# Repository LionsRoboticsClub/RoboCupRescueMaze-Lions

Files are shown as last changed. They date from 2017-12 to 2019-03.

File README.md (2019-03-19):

# RoboCupRescueMaze-Lions DONE TMR 201X
RoboCup Rescue Maze 

//CAD Render 2 months before final prototype -> https://autode.sk/2EDeenq

TODO ---- Add new Online Render 

This Repository holds all the data regarding the Lions RC Maze Robot - 2018.

Some of the content that can be found here is: 

PCBs
  Eagle files
  Gerber files
Arduino Code
  Classes
  Main
CADs
  Each piece is uploaded here for further reference and 3D printing

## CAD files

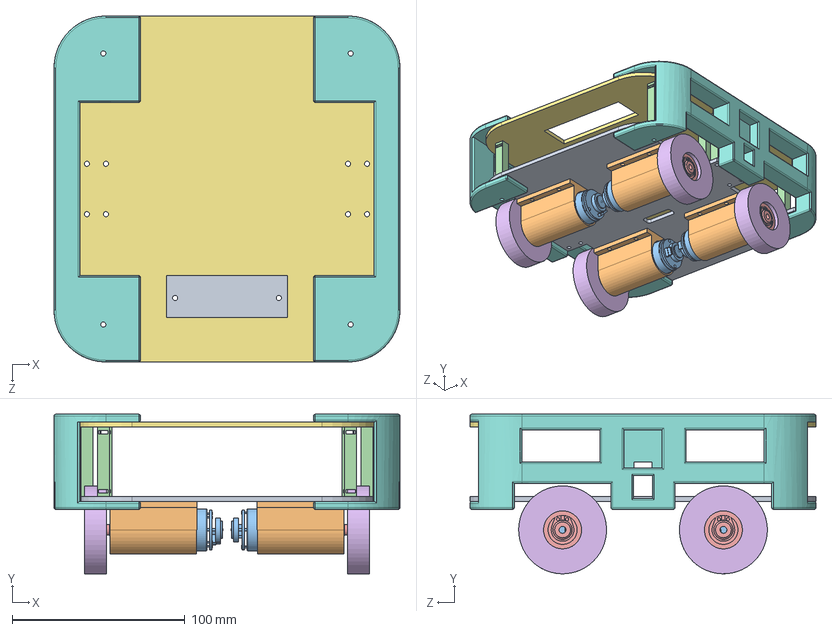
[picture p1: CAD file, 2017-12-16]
Cads/MazeRobot.SLDASM
200.0 x 92.3 x 200.0 mm
MazeBase
pololuMotorHolder x 4
Pololu 25D gear motor with encoder part no 2275 x 4
poste x 12
Snap_Hub_4mmx050 x 4
wheel x 4
MazeTop
LateralBumper x 2

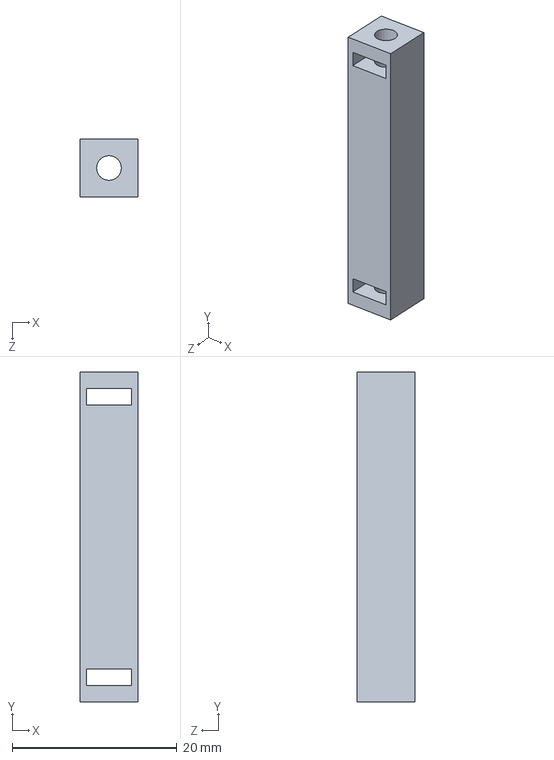
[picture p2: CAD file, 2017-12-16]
Cads/poste.SLDPRT
7.00 x 40.0 x 7.00 mm

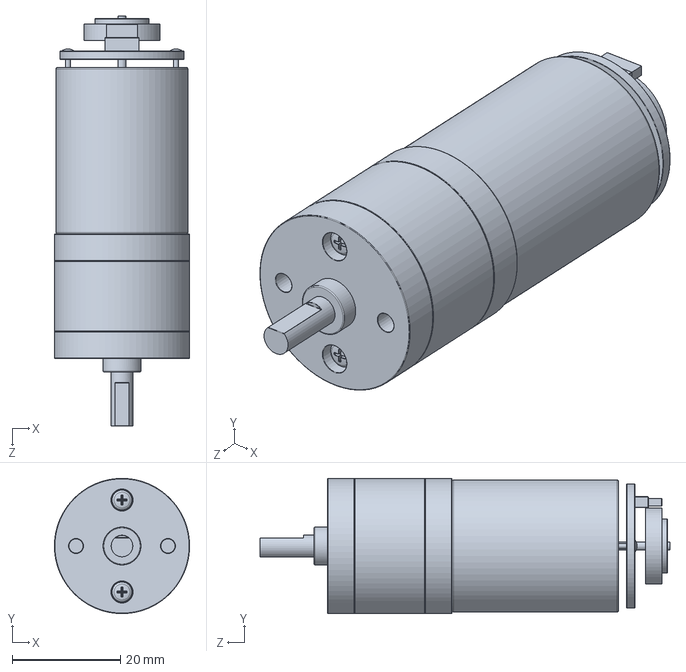
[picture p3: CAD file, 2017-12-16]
Cads/Pololu 25D gear motor with encoder part no 2275.SLDPRT
25.0 x 25.0 x 75.8 mm

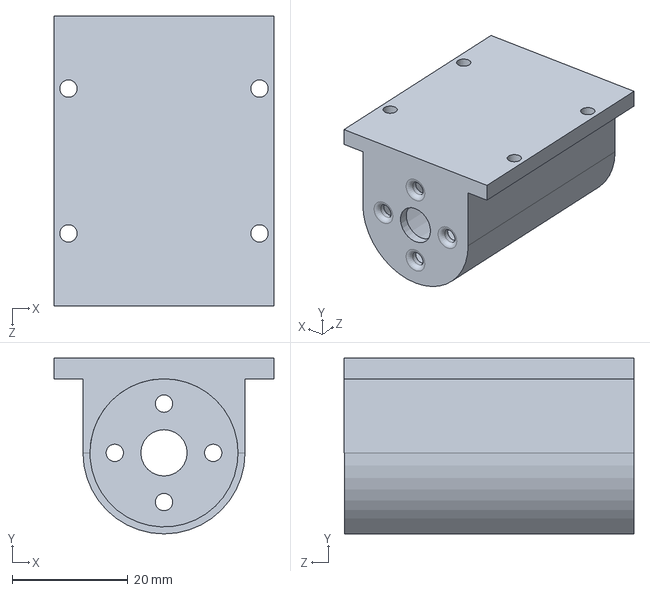
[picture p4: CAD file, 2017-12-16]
Cads/pololuMotorHolder.SLDPRT
38.0 x 30.4 x 50.0 mm

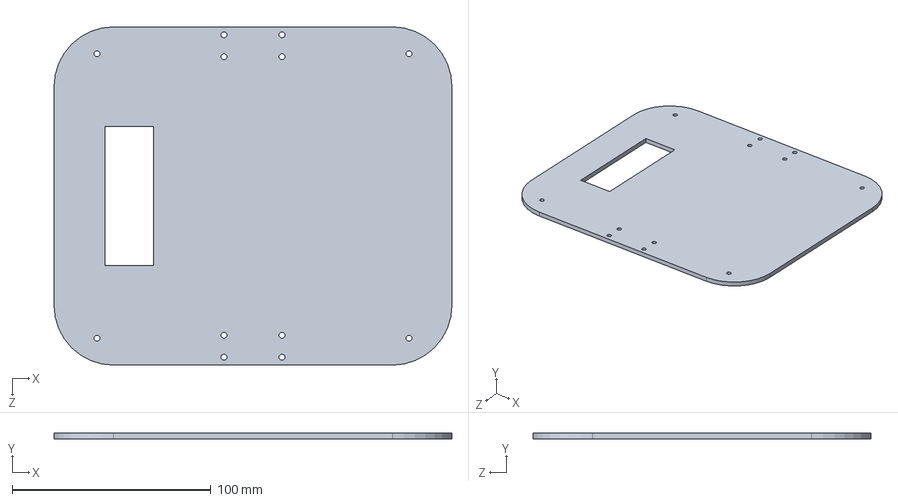
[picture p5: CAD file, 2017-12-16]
Cads/MazeTop.SLDPRT
200.0 x 3.00 x 170.0 mm

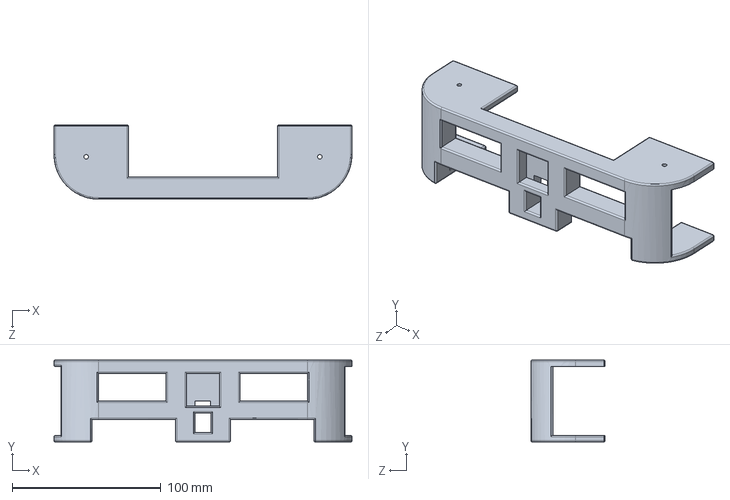
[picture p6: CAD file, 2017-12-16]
Cads/LateralBumper.SLDPRT
200.0 x 55.0 x 50.0 mm

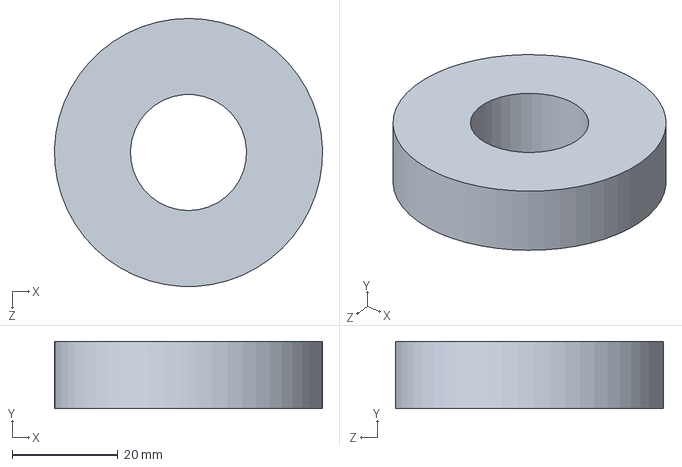
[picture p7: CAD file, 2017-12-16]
Cads/wheel.SLDPRT
50.8 x 12.7 x 50.8 mm

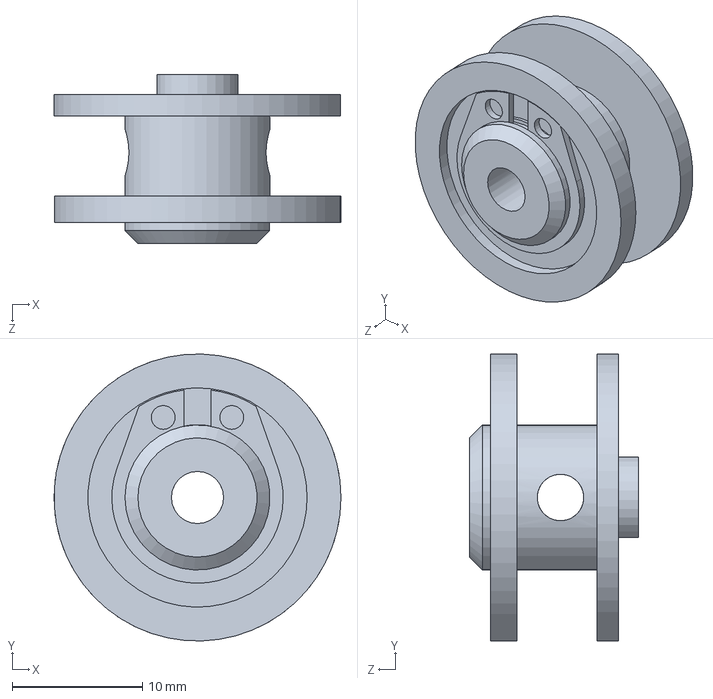
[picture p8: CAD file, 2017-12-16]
Cads/Snap_Hub_4mmx050.SLDPRT
22.0 x 22.0 x 13.0 mm

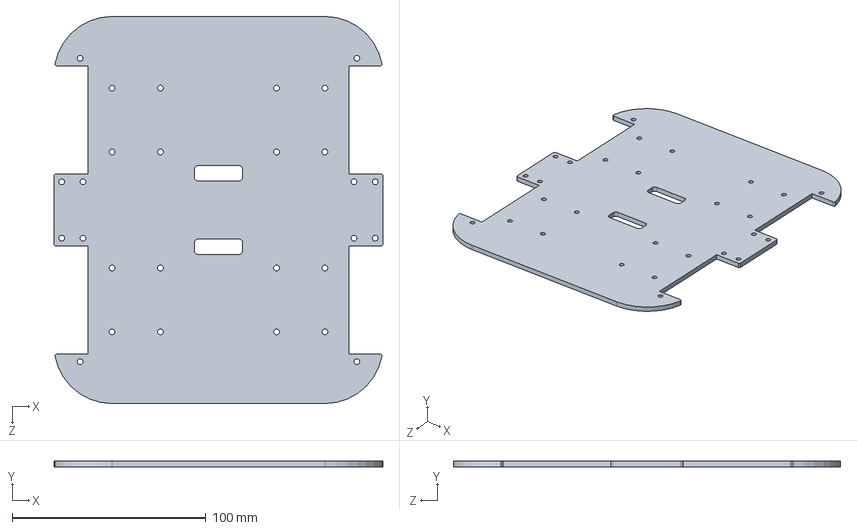
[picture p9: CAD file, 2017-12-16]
Cads/MazeBase.SLDPRT
170.0 x 3.00 x 200.0 mm

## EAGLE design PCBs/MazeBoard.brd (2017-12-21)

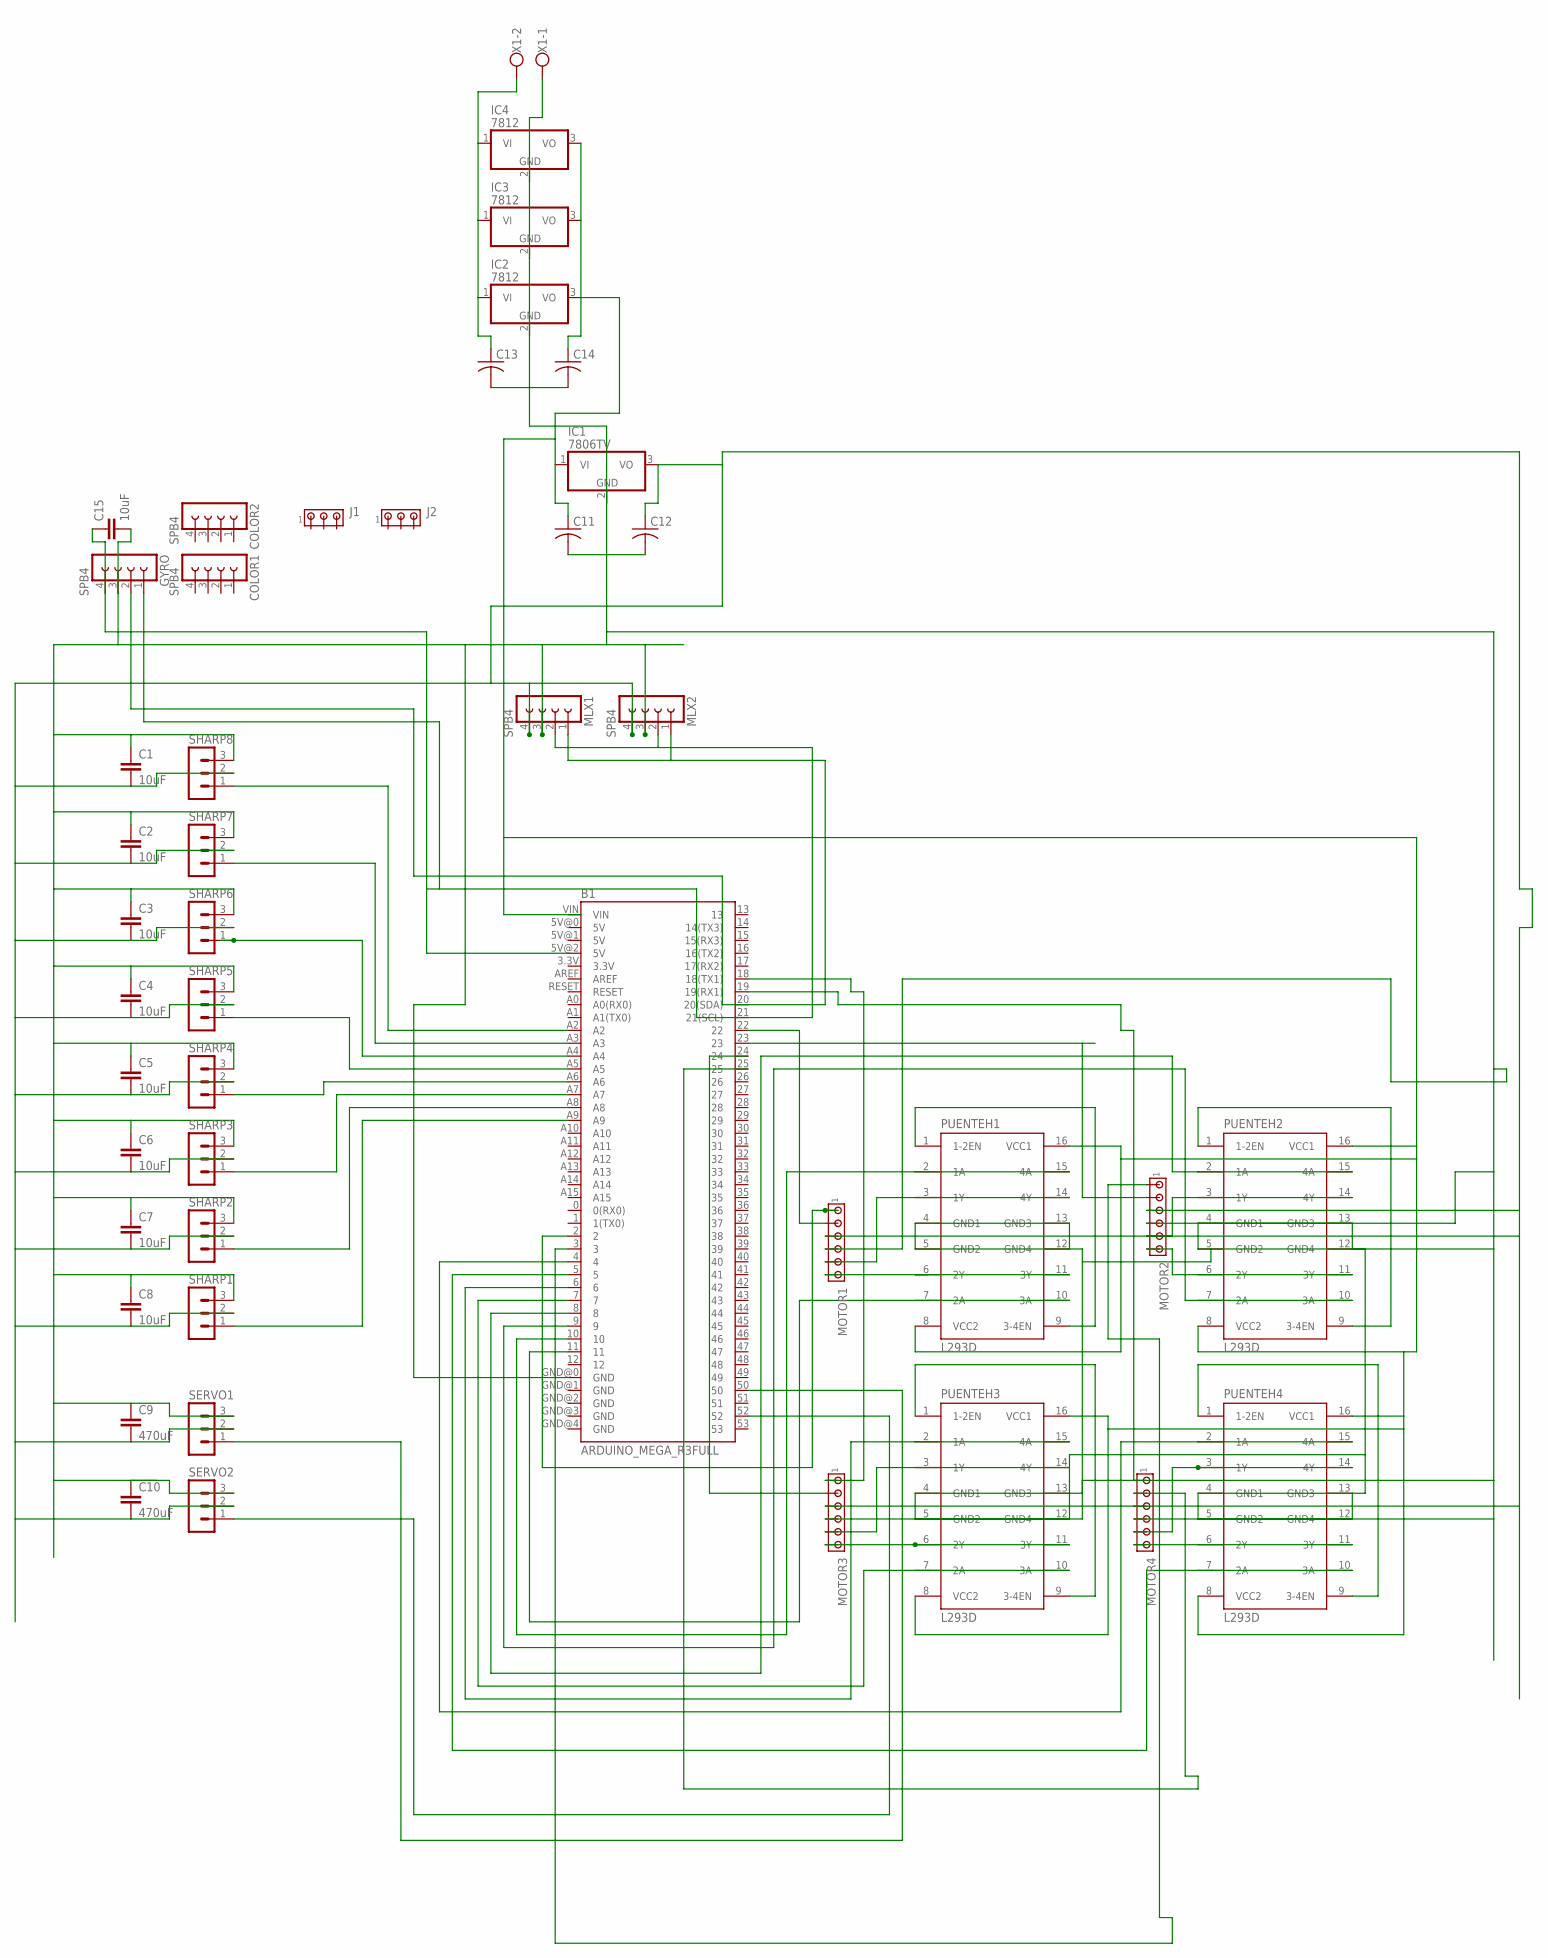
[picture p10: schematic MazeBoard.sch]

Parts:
B1: ARDUINO_MEGA_R3FULL; ARDUINO_MEGA
C1, C2, C3, C4, C5, C6, C7, C8, C15: 10uF; C2.5-3
C9, C10: 470uF; C2.5-3
C11, C12, C13, C14: C-US025-024X044; C025-024X044
COLOR1, COLOR2: SPB4
GYRO: SPB4
IC1: 7806TV; TO220V
IC2, IC3, IC4: 7812; TO220V
J1, J2: MTA03-100; 10X03MTA
MLX1, MLX2: SPB4
MOTOR1, MOTOR2, MOTOR3, MOTOR4: MTA06-100; 10X06MTA
PUENTEH1, PUENTEH2, PUENTEH3, PUENTEH4: L293D; DIL16
SERVO1, SERVO2: MA03-1
SHARP1, SHARP2, SHARP3, SHARP4, SHARP5, SHARP6, SHARP7, SHARP8: MA03-1
X1: W237-102

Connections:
6V: C1.2, C2.2, C3.2, C4.2, C5.2, C6.2, C7.2, C8.2, C9.2, C10.2, C12.1, IC1.3 (VO), MLX1.4, MLX2.4, MOTOR1.3, MOTOR2.3, MOTOR3.3, MOTOR4.3, SERVO1.2, SERVO2.2, SHARP1.2, SHARP2.2, SHARP3.2, SHARP4.2, SHARP5.2, SHARP6.2, SHARP7.2, SHARP8.2
GND: B1.GND@0 (GND), C1.1, C2.1, C3.1, C4.1, C5.1, C6.1, C7.1, C8.1, C9.1, C10.1, C11.2, C12.2, C13.2, C14.2, C15.2, GYRO.3, IC1.2 (GND), IC2.2 (GND), IC3.2 (GND), IC4.2 (GND), MLX1.3, MLX2.3, MOTOR1.4, MOTOR2.4, MOTOR3.4, MOTOR4.4, PUENTEH1.4 (GND1), PUENTEH1.5 (GND2), PUENTEH1.12 (GND4), PUENTEH1.13 (GND3), PUENTEH2.4 (GND1), PUENTEH2.5 (GND2), PUENTEH2.12 (GND4), PUENTEH2.13 (GND3), PUENTEH3.4 (GND1), PUENTEH3.5 (GND2), PUENTEH3.12 (GND4), PUENTEH3.13 (GND3), PUENTEH4.4 (GND1), PUENTEH4.5 (GND2), PUENTEH4.12 (GND4), PUENTEH4.13 (GND3), SERVO1.3, SERVO2.3, SHARP1.3, SHARP2.3, SHARP3.3, SHARP4.3, SHARP5.3, SHARP6.3, SHARP7.3, SHARP8.3, X1.1
unnamed: B1.A4, SHARP6.1
unnamed: B1.A5, SHARP5.1
unnamed: B1.A6, SHARP4.1
unnamed: B1.A7, SHARP3.1
unnamed: B1.A2, SHARP8.1
unnamed: B1.A3, SHARP7.1
unnamed: B1.A8, SHARP2.1
unnamed: B1.A9, SHARP1.1
unnamed: B1.52, SERVO2.1
unnamed: B1.3, MOTOR2.1
unnamed: B1.21 (21(SCL)), GYRO.1, MLX1.2, MLX2.2
unnamed: B1.20 (20(SDA)), GYRO.2, MLX1.1, MLX2.1
unnamed: B1.5V@2 (5V), C15.1, GYRO.4
unnamed: PUENTEH1.1 (1-2EN), PUENTEH1.9 (3-4EN)
unnamed: MOTOR3.6, PUENTEH3.6 (2Y), PUENTEH3.11 (3Y)
unnamed: MOTOR3.5, PUENTEH3.3 (1Y), PUENTEH3.14 (4Y)
unnamed: MOTOR4.6, PUENTEH4.6 (2Y), PUENTEH4.11 (3Y)
unnamed: MOTOR4.5, PUENTEH4.3 (1Y), PUENTEH4.14 (4Y)
unnamed: MOTOR1.6, PUENTEH1.6 (2Y), PUENTEH1.11 (3Y)
unnamed: MOTOR1.5, PUENTEH1.3 (1Y), PUENTEH1.14 (4Y)
unnamed: MOTOR2.5, PUENTEH2.3 (1Y), PUENTEH2.14 (4Y)
unnamed: MOTOR2.6, PUENTEH2.6 (2Y), PUENTEH2.11 (3Y)
unnamed: PUENTEH3.1 (1-2EN), PUENTEH3.9 (3-4EN)
unnamed: PUENTEH4.1 (1-2EN), PUENTEH4.9 (3-4EN)
unnamed: B1.7, PUENTEH3.7 (2A), PUENTEH3.10 (3A)
unnamed: B1.6, PUENTEH3.2 (1A), PUENTEH3.15 (4A)
unnamed: B1.4, PUENTEH4.2 (1A), PUENTEH4.15 (4A)
unnamed: B1.5, PUENTEH4.7 (2A), PUENTEH4.10 (3A)
unnamed: B1.11, PUENTEH1.7 (2A), PUENTEH1.10 (3A)
unnamed: B1.10, PUENTEH1.2 (1A), PUENTEH1.15 (4A)
unnamed: B1.2, MOTOR1.1
unnamed: B1.9, PUENTEH2.7 (2A), PUENTEH2.10 (3A)
unnamed: PUENTEH2.1 (1-2EN), PUENTEH2.9 (3-4EN)
unnamed: B1.18 (18(TX1)), MOTOR3.1
unnamed: B1.19 (19(RX1)), MOTOR4.1
unnamed: B1.50, SERVO1.1
unnamed: B1.22, MOTOR1.2
unnamed: B1.8, PUENTEH2.2 (1A), PUENTEH2.15 (4A)
unnamed: B1.24, MOTOR3.2
unnamed: B1.25, MOTOR4.2
unnamed: B1.23, MOTOR2.2
unnamed: C11.1, C14.1, IC1.1 (VI), IC2.3 (VO), IC3.3 (VO), IC4.3 (VO), PUENTEH1.8 (VCC2), PUENTEH1.16 (VCC1), PUENTEH2.8 (VCC2), PUENTEH2.16 (VCC1), PUENTEH3.8 (VCC2), PUENTEH3.16 (VCC1), PUENTEH4.8 (VCC2), PUENTEH4.16 (VCC1)
unnamed: C13.1, IC2.1 (VI), IC3.1 (VI), IC4.1 (VI), X1.2

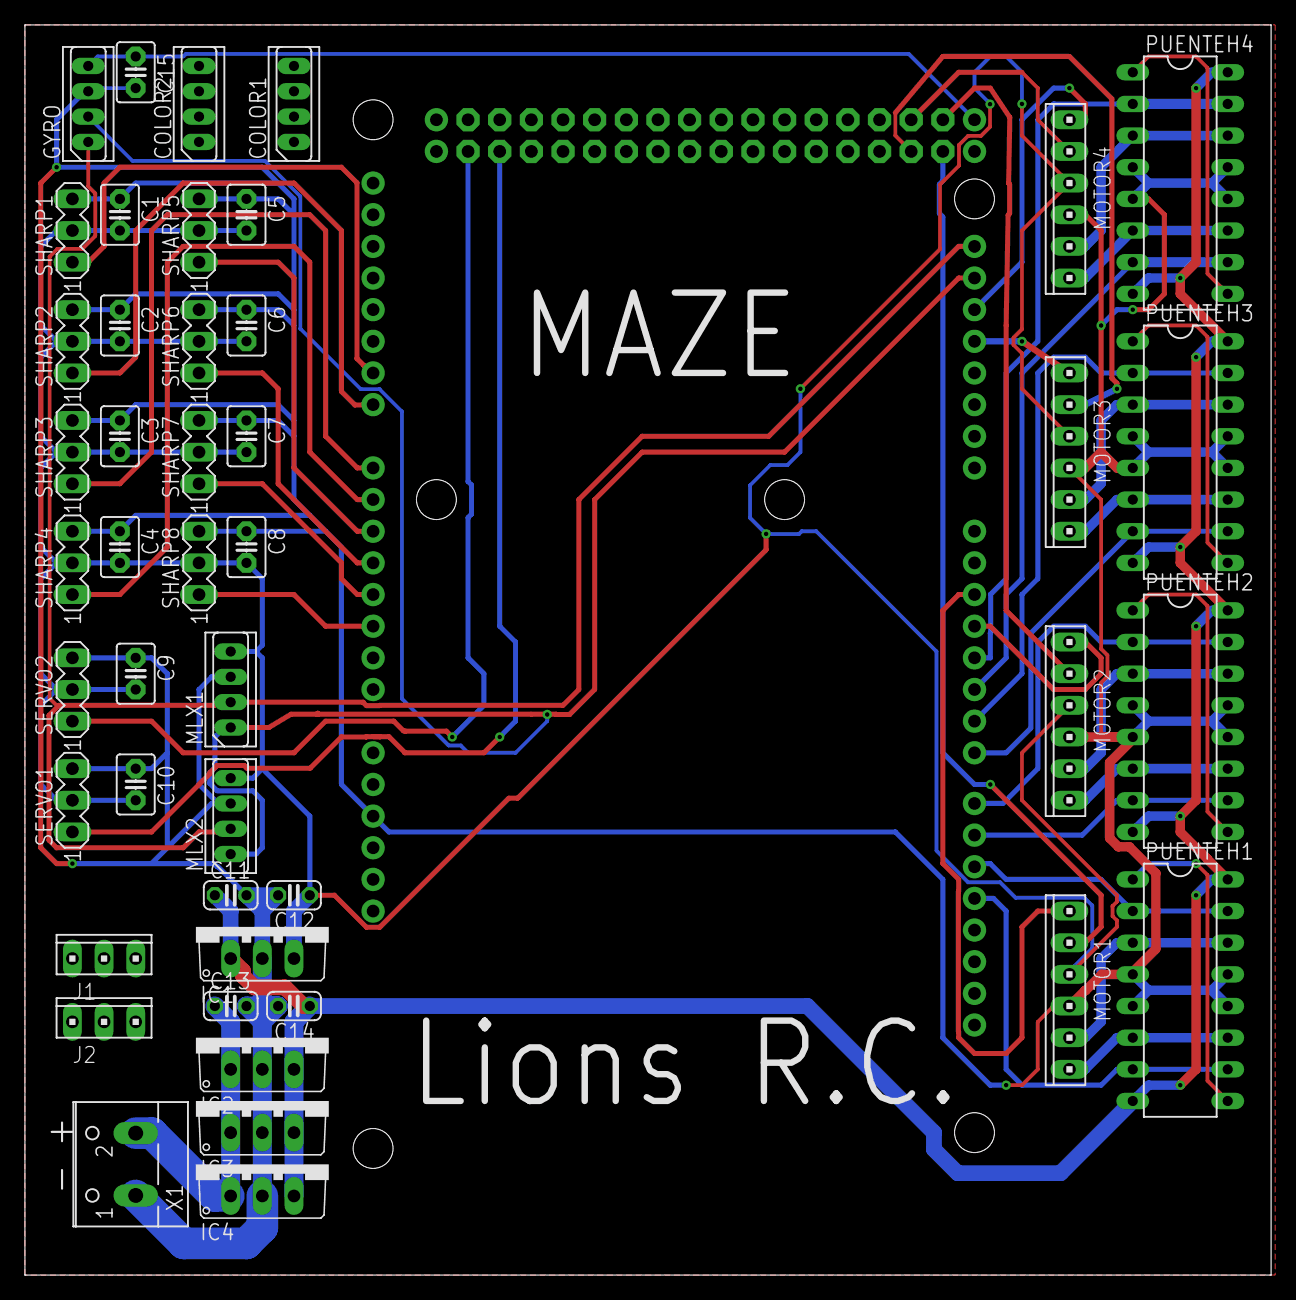
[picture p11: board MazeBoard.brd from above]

Board: 2 copper layers, 100.0 x 100.3 mm, 46 parts (1 on the bottom side), 45 nets.

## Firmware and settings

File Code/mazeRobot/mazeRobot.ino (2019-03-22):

//#include <i2cmaster.h>
//#include <Adafruit_TCS34725.h>
#include <EnableInterrupt.h>
#include <NewPing.h>
#include <Wire.h>


/*--------------------------------------
*
*
*         GLOBAL VARIABLES
*
*
----------------------------------------
*/

int mazeSizeX = 7;
int mazeSizeY = 7;

int mazeSizeX2 = 7;
int mazeSizeY2 = 7;


int robotStartPosX = 0;
int robotStartPosY = 6;

int luxBlack = 100;
int luxWhite = 700;
int luxCheckpoint = 700;

Nextion myNextion;

void checkCheckpointButton();

/*--------------------------------------
*
*
*         SENSORS
*
*
----------------------------------------
*/

/*--------------------------------------
  Class ColorSensor
*/

class ColorSensor
{
public:
  ColorSensor();

  byte calculateColor();

private:
  //Adafruit_TCS34725 tcs;
  byte redPin, greenPin, bluePin;
};

ColorSensor::ColorSensor()
{
  //tcs = Adafruit_TCS34725(TCS34725_INTEGRATIONTIME_700MS, TCS34725_GAIN_1X);
  //tcs.begin();

  
}

byte ColorSensor::calculateColor()
{
  return 1;
}
//-------------------------------------------------

/*--------------------------------------
  Class LimitSwitch
*/
class LimitSwitch
{
  public:
    LimitSwitch(byte);
    int isPushed();
  private:
    int pin;
};

LimitSwitch::LimitSwitch(byte addPin)
{
  pin = addPin;
  pinMode(pin, INPUT);
}

int LimitSwitch::isPushed()
{
  int value = analogRead(pin);

  return value;
}
//-------------------------------------------------

/*--------------------------------------
  Class Thermometer
*/

class Thermometer
{
public: 
  Thermometer(int ad);
  float getTemperature();

private: 
  float temperature;
  int address;
};

Thermometer::Thermometer(int ad)
{
  address = ad;
}
/*
float Thermometer::getTemperature()
{
  int melexisAddress = address<<1;
  int dev = melexisAddress; 
  int data_low = 0; 
  int data_high = 0; 
  int pec = 0;

  //write
  i2c_start_wait(dev + I2C_WRITE);
  i2c_write(0x07);

  //read
  i2c_rep_start(dev+I2C_READ);
  data_low = i2c_readAck();
  data_high = i2c_readAck();
  pec = i2c_readNak();
  i2c_stop();
  double tempFactor = 0.02;
  double tempData = 0x0000;
  int frac;
  tempData = (double)(((data_high & 0x007F) << 8) + data_low);
  tempData = (tempData * tempFactor)-0.01;
  float temperature = tempData - 273.15;
  return temperature;
}

float temperatureCelcius(int address) 
{
  int dev = address;
  int data_low = 0;
  int data_high = 0;
  int pec = 0;

  // Write
  i2c_start_wait(dev+I2C_WRITE);
  i2c_write(0x07);

  // Read
  i2c_rep_start(dev+I2C_READ);
  data_low = i2c_readAck();
  data_high = i2c_readAck();
  pec = i2c_readNak();
  i2c_stop();
  double tempFactor = 0.02;
  double tempData = 0x0000;
  int frac;
  tempData = (double)(((data_high & 0x007F) << 8) + data_low);
  tempData = (tempData * tempFactor)-0.01;
  float celcius = tempData - 273.15;
  return celcius;
}*/
//---------------------------------------

/*---------------------------------------
  Class DigitalSharp
*/

class DigitalSharp
{
  public:
    DigitalSharp(byte);

    bool isInRange();

  private:
    byte pin;
};

DigitalSharp::DigitalSharp(byte addPin)
{
  pin = addPin;
  pinMode(pin, INPUT);
}

bool DigitalSharp::isInRange()
{
  return !digitalRead(pin);
}

//--------------------------------------

/*---------------------------------------
  Class Ultrasonic
*/

class Ultrasonic
{
  public:
    Ultrasonic(byte);

    float getDistance();

  private:
    int pingPin;
    NewPing sonar;

};

Ultrasonic::Ultrasonic(byte pin) :
  sonar(pin, pin)
{
  pingPin = pin;
}

float Ultrasonic::getDistance()
{
  unsigned int microSec = sonar.ping();
  return float(microSec) / (US_ROUNDTRIP_CM);
}


//--------------------------------------

/*--------------------------------------
*
*
*         MOTORS AND CONTROL
*
*
----------------------------------------
*/

/*---------------------------------------
  Class Motor
*/

class Motor
{
  public:
    Motor(byte, byte, byte, byte);

    int getEncoderA() {
      return encoderA;
    }
    int getEncoderB() {
      return encoderB;
    }
    unsigned long getOldPos() {
      return oldPos;
    }
    int getLastStateA() {
      return lastStateA;
    }
    unsigned long getEncoderPos() {
      return encoderPos;
    }

    void setEncoderPos(unsigned long long pos) {
      encoderPos = pos;
    }
    void setLastStateA(int state) {
      lastStateA = state;
    }

    void increaseEncoderPos() {
      encoderPos++;
    }

    void increaseEncoderTotalTurnPos() {
      encoderTotalTurnPos++;
    }

    void resetEncoderTotalTurnPos() {
      encoderTotalTurnPos = 0;
    }

    unsigned long getEncoderTotalTurnPos() {
      return encoderTotalTurnPos;
    }

    float calculateSpeed();
    void forward(int intensity);
    void backward(int intensity);
    void stopMotor();

  private:
    int pinForward;
    int pinBackward;
    int encoderA;
    int encoderB;
    float speed;

    volatile unsigned long encoderPos;
    volatile int currentState = LOW;
    volatile int lastStateA  = LOW;

    unsigned long oldTime;
    unsigned long oldPos;
    unsigned long encoderTotalTurnPos;
};

Motor::Motor(byte pin1, byte pin2, byte eA, byte eB)
{
  pinForward = pin1;
  pinBackward = pin2;

  encoderA = eA;
  encoderB = eB;

  pinMode(pinForward, OUTPUT);
  pinMode(pinBackward, OUTPUT);

  pinMode(encoderA, INPUT);
  digitalWrite(encoderA, HIGH);

  pinMode(encoderB, INPUT);
  digitalWrite(encoderB, HIGH);

  speed = 0;
  encoderPos = 0;

  oldTime = 0;
  oldPos;

  encoderTotalTurnPos = 0;
}

float Motor::calculateSpeed()
{
  unsigned long long newTime = millis();

  //newTime = newTime % 10000007;
  speed = ((encoderPos - oldPos) * 1000) / ((float)(newTime - oldTime));
  oldTime = newTime;
  oldPos = encoderPos;
  return speed;
}

void Motor::forward(int intensity)
{
  analogWrite(pinForward, intensity);
  analogWrite(pinBackward, 0);
}

void Motor::backward(int intensity)
{
  analogWrite(pinForward, 0);
  analogWrite(pinBackward, intensity);
}

void Motor::stopMotor()
{
  analogWrite(pinForward, 0);
  analogWrite(pinBackward, 0);
}


//------------------------------------------------

/*-----------------------------------------------
Class Control
*/

class Control
{
public:
  Control();

  Motor& getMotor1() {return motor1;}
  Motor& getMotor2() {return motor2;}
  Motor& getMotor3() {return motor3;}
  Motor& getMotor4() {return motor4;}

  Ultrasonic getUltraSensorRight() {return ultraSensorRight;}
  Ultrasonic getUltraSensorLeft() {return ultraSensorLeft;}
  Ultrasonic getUltraSensorFront() {return ultraSensorFront;}

  LimitSwitch getLimitSwitchA(){return LimitSwitchA;}
  LimitSwitch getLimitSwitchB(){return LimitSwitchB;}
  LimitSwitch getLimitSwitchC(){return LimitSwitchC;}
  LimitSwitch getLimitSwitchD(){return LimitSwitchD;}

  Thermometer getTempSensorRight(){return tempSensorRight;}
  Thermometer getTempSensorLeft(){return tempSensorLeft;}

  //ColorSensor getColorSensor() {return colorSensor;}

  float getFrontDistace() {return frontDistance;}
  void setFrontDistance(float distance) {frontDistance = distance;}

  void forwardMotors(byte);
  void backwardMotors(byte);
  void stopMotors();

  //Simple motor rotation only
  void rotateRight(byte);
  void rotateLeft(byte);

  //90 degree rotation
  void turnRight(byte);
  void turnLeft(byte);
  
  int forwardTile(byte);
  void alignForward(byte);
  void alignBackward(byte);
  void backFiveCm(byte);
  void forwardFiveCm(byte);

  void backFromBlack(byte);

  void goUpRamp(byte, bool);

  Motor motor1;
  Motor motor2;
  Motor motor3;
  Motor motor4;
private:

  LimitSwitch LimitSwitchA;
  LimitSwitch LimitSwitchB;
  LimitSwitch LimitSwitchC;
  LimitSwitch LimitSwitchD;
  

  Ultrasonic ultraSensorRight;
  Ultrasonic ultraSensorLeft;
  Ultrasonic ultraSensorFront;

  Thermometer tempSensorRight;
  Thermometer tempSensorLeft;

  ColorSensor colorSensor;

  int turn90amount;
  int back5amount;
  int forward30amount;
  float frontDistance;

};


Control::Control() :
motor1(4,5,19,25), motor2(7,6,18,24), motor3(9,8,3,23), motor4(10,11,2,22),
ultraSensorRight(A9), ultraSensorLeft(A8), ultraSensorFront(A3), LimitSwitchA(A13), LimitSwitchB(27), LimitSwitchC(29), 
LimitSwitchD(A12), tempSensorRight(0x1B), tempSensorLeft(0x2B), colorSensor()
{
  turn90amount = 900;
  forward30amount = 1520;
  back5amount = (forward30amount/6);
  frontDistance = 0;
}

void Control::forwardMotors(byte intensity)
{
  motor1.forward(intensity);
  motor2.forward(intensity);
  motor3.forward(intensity);
  motor4.forward(intensity);
}

void Control::backwardMotors(byte intensity)
{
  motor1.backward(intensity);
  motor2.backward(intensity);
  motor3.backward(intensity);
  motor4.backward(intensity);
}

void Control::stopMotors()
{
  motor1.stopMotor();
  motor2.stopMotor();
  motor3.stopMotor();
  motor4.stopMotor();
}

void Control::rotateRight(byte intensity)
{
  motor1.backward(intensity);
  motor4.backward(intensity);
  motor3.forward(intensity);
  motor2.forward(intensity);
}

void Control::rotateLeft(byte intensity)
{
  motor1.forward(intensity);
  motor4.forward(intensity);
  motor3.backward(intensity);
  motor2.backward(intensity);
}

void Control::turnRight(byte intensity)
{
  motor1.resetEncoderTotalTurnPos();
  motor2.resetEncoderTotalTurnPos();
  motor3.resetEncoderTotalTurnPos();
  motor4.resetEncoderTotalTurnPos();

  rotateRight(intensity);

  //Add sensor scanning in this area for more precision or obstacles 
  //NO ME GUSTAN LOS METICHES
  while (true)
  {
    if (motor1.getEncoderTotalTurnPos() > turn90amount && motor2.getEncoderTotalTurnPos() > turn90amount &&
        motor3.getEncoderTotalTurnPos() > turn90amount && motor4.getEncoderTotalTurnPos() > turn90amount)
    {
      break;
    }

    ultraSensorRight.getDistance();
    ultraSensorLeft.getDistance();
    ultraSensorFront.getDistance();

    delay(5);
  }
  

  stopMotors();
}

void Control::goUpRamp(byte intensity, bool isUp)
{
  if (isUp)
  {
    forwardMotors(intensity);

    while (true)
    {
      if (true)//gyroSensor.getInclination() > 5)
      {
        break;
      }
    }

    while (true)
    {
      if (true)//gyroSensor.getInclination() < 5)
      {
        break;
      }
    }
  }
  else
  {
    while (true)
    {
      if (true)//gyroSensor.getInclination() < -5)
      {
        break;
      }
    }

    while (true)
    {
      if (true)//gyroSensor.getInclination() > -5)
      {
        break;
      }
    }
  }

  stopMotors();
}

void Control::backFiveCm(byte intensity)
{
  motor1.resetEncoderTotalTurnPos();
  motor2.resetEncoderTotalTurnPos();
  motor3.resetEncoderTotalTurnPos();
  motor4.resetEncoderTotalTurnPos();

  backwardMotors(intensity);
  
  //Add sensor scanning in this area for more precision or obstacles
  while (true)
  {
    if (motor1.getEncoderTotalTurnPos() > back5amount && motor2.getEncoderTotalTurnPos() > back5amount &&
        motor3.getEncoderTotalTurnPos() > back5amount && motor4.getEncoderTotalTurnPos() > back5amount)
    {
      break;
    }
    
    delay(5);


  }

  stopMotors();
}

void Control::forwardFiveCm(byte intensity)
{
  motor1.resetEncoderTotalTurnPos();
  motor2.resetEncoderTotalTurnPos();
  motor3.resetEncoderTotalTurnPos();
  motor4.resetEncoderTotalTurnPos();

  forwardMotors(intensity);
  
  //Add sensor scanning in this area for more precision or obstacles
  while (true)
  {
    if (motor1.getEncoderTotalTurnPos() > back5amount && motor2.getEncoderTotalTurnPos() > back5amount &&
        motor3.getEncoderTotalTurnPos() > back5amount && motor4.getEncoderTotalTurnPos() > back5amount)
    {
      break;
    }
    
    delay(5);


  }

  stopMotors();
}

void Control::turnLeft(byte intensity)
{
  motor1.resetEncoderTotalTurnPos();
  motor2.resetEncoderTotalTurnPos();
  motor3.resetEncoderTotalTurnPos();
  motor4.resetEncoderTotalTurnPos();

  rotateLeft(intensity);

  //Add sensor scanning in this area for more precision or obstacles
  while (true)
  {
    if (motor1.getEncoderTotalTurnPos() > turn90amount && motor2.getEncoderTotalTurnPos() > turn90amount &&
        motor3.getEncoderTotalTurnPos() > turn90amount && motor4.getEncoderTotalTurnPos() > turn90amount)
    {
      break;
    }
    
    ultraSensorRight.getDistance();
    ultraSensorLeft.getDistance();
    ultraSensorFront.getDistance();
    
    delay(5);
  }

  stopMotors();
}

void Control::alignForward(byte intensity)
{
  forwardMotors(intensity);

  while(true)
  {
    if(LimitSwitchA.isPushed()==LimitSwitchD.isPushed() && LimitSwitchA.isPushed() > 1000 && LimitSwitchB.isPushed() > 1000 && ultraSensorFront.getDistance()<2)
    {
      break;
    }
  }
}

void Control::alignBackward(byte intensity)
{
  backwardMotors(intensity);

  while(true)
  {
    delay(1000);
    break;
  }
}

void Control::backFromBlack(byte intensity)
{
  unsigned long targetPosM1 = motor1.getEncoderTotalTurnPos()*2;
  unsigned long targetPosM2 = motor2.getEncoderTotalTurnPos()*2;
  unsigned long targetPosM3 = motor3.getEncoderTotalTurnPos()*2;
  unsigned long targetPosM4 = motor4.getEncoderTotalTurnPos()*2;

  backwardMotors(intensity);

  while(true)
  {
    if (motor1.getEncoderTotalTurnPos() > targetPosM1 && motor2.getEncoderTotalTurnPos() > targetPosM2 &&
        motor3.getEncoderTotalTurnPos() > targetPosM3 && motor4.getEncoderTotalTurnPos() > targetPosM4)
    {
      break;
    }
  }
}

int Control::forwardTile(byte intensity)
{
  motor1.resetEncoderTotalTurnPos();
  motor2.resetEncoderTotalTurnPos();
  motor3.resetEncoderTotalTurnPos();
  motor4.resetEncoderTotalTurnPos();

  forwardMotors(intensity);

  int returnValue = 0;
  
  //Add sensor scanning in this area for more precision or obstacles
  while (true)
  {
    if (motor1.getEncoderTotalTurnPos() > forward30amount && motor2.getEncoderTotalTurnPos() > forward30amount &&
        motor3.getEncoderTotalTurnPos() > forward30amount && motor4.getEncoderTotalTurnPos() > forward30amount &&
        (int)ultraSensorFront.getDistance() < frontDistance - 30)
    {
      frontDistance -= 30;
      stopMotors();
      return colorSensor.calculateColor();
    }

    if (colorSensor.calculateColor() == 2)
    {
      backFromBlack(intensity);
      return 2;
    }

    //If there is a ramp
    if (false)//control.getGyroScope().getInclination() > 5)
    {
      backFromBlack(intensity);
      return 4;
    }

    ultraSensorRight.getDistance();
    ultraSensorLeft.getDistance();
    ultraSensorFront.getDistance();
    
    delay(5);

  }

}

/*--------------------------------------
*
*
*         NAVIGATION, WALLS, AND TILES
*
*
----------------------------------------
*/
/*--------------------------------------
Class Wall
*/

class Wall
{
public:
  Wall();

  void setWallExists(bool value) {wallExists = value;}
  void setHeatedVictim(bool value) {heatedVictim = value;}
  void setHarmedVictim(bool value) {harmedVictim = value;}
  void setStableVictim(bool value) {stableVictim = value;}
  void setUnharmedVictim(bool value) {unharmedVictim = value;}

  bool getWallExists() {return wallExists;}
  bool getHeatedVictim() {return heatedVictim;}
  bool getHarmedVictim() {return harmedVictim;}
  bool getStableVictim() {return stableVictim;}
  bool getUnharmedVictim() {return unharmedVictim;}

private:

  bool wallExists;
  bool heatedVictim, harmedVictim, stableVictim, unharmedVictim;
};

Wall::Wall()
{
  wallExists = false;
  heatedVictim = false;
  harmedVictim = false;
  stableVictim = false;
  unharmedVictim = false;
}
//--------------------------------------

/*--------------------------------------
Class Tile
*/
class Tile
{
public:
  Tile();

  byte getX() {return x;}
  byte getY() {return y;}

  void setX(byte nx) {x = nx;}
  void setY(byte ny) {y = ny;}
  void setIsVisited(bool value) {isVisited = value;}
  void setIsRobotPresent(bool value) {isRobotPresent = value;}
  void setIsNode(bool value) {isNode = value;}
  void setFloorType(byte type) {floorType = type;}
  void setSearchNumber(byte number) {searchNumber = number;}
  void setTraceNumber(byte number) {traceNumber = number;}
  void setTemperature(float temp) {temperature = temp;}
  void setIsRamp(bool value) {isRamp = value;}

  bool getIsVisited() {return isVisited;}
  bool getIsNode() {return isNode;}
  bool getIsRobotPresent() {return isRobotPresent;}
  byte getFloorType() {return floorType;}
  byte getSearchNumber() {return searchNumber;}
  byte getTraceNumber() {return traceNumber;}
  float getTemperature() {return temperature;}
  bool getIsRamp() {return isRamp;}

  Wall wallNorth;
  Wall wallEast;
  Wall wallWest;
  Wall wallSouth;

private:
  byte x;
  byte y;

  bool isVisited, isNode, isRobotPresent;
  bool isRamp;
  byte floorType;
  byte searchNumber;
  byte traceNumber;

 float temperature;

};

Tile::Tile()
{
  isVisited = false;
  isNode = false;
  isRobotPresent = false;
  isRamp = false;

  floorType = 0;
  searchNumber = 100;
  traceNumber = 0;

}
//--------------------------------------

/*--------------------------------------
Class Navigation
*/
class Navigation
{
public:

  static void start(byte matSize);

  static void scanSides();
  static void scanForVictims();
  
  static void decideToTraceNumber();

  static void moveToNextTile();
  static void adjustToNextMove();
  static Control& getControl() {return control;}

  static byte getRobotPosX() {return robotPosX;}
  static byte getRobotPosY() {return robotPosY;}
  static byte getNodePosX() {return nodePosX;}
  static byte getNodePosY() {return nodePosY;}
  static byte getNodeAmount() {return nodeAmount;}
  static bool getNodeMode() {return nodeMode;}
  static bool getMazeComplete() {return mazeComplete;}
  static bool getActivateNode() {return activateNode;}
  static bool getDone() {return done;}
  static bool getInMainMaze() {return inMainMaze;}
  static bool getToSecondMaze() {return toSecondMaze;}
  static bool getBackToMain() {return backToMain;}

  static void findClosestNode();
  static void tracePath();

  static void backToHome();
  static void changeMaze();

  static void restartToCheckPoint();
  static void saveCheckpoint();

  static void checkNodeMode();
  static void eraseNodes();
  static Control control;

private:
  enum robotOrientation {North, South, East, West};
  enum possibleMoves {MoveForward, TurnRight, TurnLeft, DeadEnd};

  static byte robotPosX;
  static byte robotPosY;

  static robotOrientation orientation;
  static robotOrientation rampOrientation;

  static possibleMoves nextMove;
  static possibleMoves rampMove;

  static Tile tiles[7][7];
  static Tile tiles2[7][7];
  static Tile tilesCheck[7][7];

  static byte intensity;

  static bool nodeMode;
  static bool mazeComplete;
  static bool activateNode;
  static bool inMainMaze;
  static bool maze2Complete;
  static bool backToMain;
  static bool toSecondMaze;
  static bool done;
  static bool thereIsRamp;

  static byte currentSearchNumber;
  static byte nodePosX;
  static byte nodePosY;

  static byte lastCheckPointPosX;
  static byte lastCheckPointPosY;

  static byte rampPosX;
  static byte rampPosY;

  static byte maze2StartPosX;
  static byte maze2StartPosY;

  static byte nodeAmount;

public:
  static possibleMoves decideNextMove(bool, bool, bool);

};

Navigation::robotOrientation Navigation::orientation = North;
Navigation::possibleMoves Navigation::nextMove = MoveForward;

Navigation::robotOrientation Navigation::rampOrientation = North;

byte Navigation::intensity = 255; 

byte Navigation::currentSearchNumber = 1;
byte Navigation::nodePosX = 0;
byte Navigation::nodePosY = 0;
byte Navigation::nodeAmount = 0;

byte Navigation::lastCheckPointPosX = 0;
byte Navigation::lastCheckPointPosY = 0;

byte Navigation::rampPosX = 0;
byte Navigation::rampPosY = 0;

byte Navigation::maze2StartPosX = 0;
byte Navigation::maze2StartPosY = 0;

byte Navigation::robotPosX = 0;
byte Navigation::robotPosY = 0;
Tile Navigation::tiles[7][7];
Tile Navigation::tiles2[7][7];
Tile Navigation::tilesCheck[7][7];
Control Navigation::control;

bool Navigation::nodeMode = false;
bool Navigation::mazeComplete = false;
bool Navigation::activateNode = true;
bool Navigation::inMainMaze = true;
bool Navigation::maze2Complete = false;
bool Navigation::backToMain = false;
bool Navigation::toSecondMaze = false;
bool Navigation::done = false;
bool Navigation::thereIsRamp = false;
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
void loop()
{
  checkCheckpointButton();
  if (!Navigation::getNodeMode())
  {
    //MAPPING NAVIGATION

    //CHECK IF DONE
    if (Navigation::getDone())
    {
      delay(10000);
    }

    //USE ULTRASONIC TO GET WALLS
    Navigation::scanSides();
    checkCheckpointButton();

    Serial2.print("n0.val=");
    Serial2.print(7);  
    Serial2.write(0xff); 
    Serial2.write(0xff);
    Serial2.write(0xff);

    //Navigation::scanForVictims();
    
    //IF NO POSSIBLE MOVE, GO NODE MODE
    if (Navigation::getNodeMode())
    {
      return;
    }
    
    delay(100);
    checkCheckpointButton();

    //ROTATE ROBOT TO MOVE
    Navigation::adjustToNextMove();
    checkCheckpointButton();

    delay(100);  

    //Navigation::scanForVictims();
    checkCheckpointButton();
    delay(50);

    //MOVE FORWARD TO NEXT TILE
    Navigation::moveToNextTile();
    checkCheckpointButton();
    delay(100);
    
  }
  else
  {
    //NODE MODE

    //CHECK IF FIRST TIME IN NODE
    if (Navigation::getActivateNode())
    {
      checkCheckpointButton();
      Navigation::findClosestNode();
      checkCheckpointButton();
      Navigation::tracePath();
      checkCheckpointButton();
    }

    //DECIDE NEXT MOVE BASED ON NUMBERS
    Navigation::decideToTraceNumber();
    checkCheckpointButton();

    //ROTATE TO NEXT MOVE
    Navigation::adjustToNextMove();
    checkCheckpointButton();

    delay(100);

    //MOVE FORWARD TO NEXT TILE
    Navigation::moveToNextTile();
    checkCheckpointButton();

    //CHECK IF DONE WITH NODES
    Navigation::checkNodeMode();
    checkCheckpointButton();

  }

  //ERASE ALREADY EXHAUSTED NODES
  Navigation::eraseNodes();

}

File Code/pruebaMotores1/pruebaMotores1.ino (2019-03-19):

#include <EnableInterrupt.h>
#include <NewPing.h>


/*---------------------------------------
Class DigitalSharp
*/

class DigitalSharp
{
public:
    DigitalSharp(int);
    
    bool isInRange();
 

 
private:
    int pin;
};

DigitalSharp::DigitalSharp(int addPin)
{
    pin = addPin;
    pinMode(pin, INPUT);
}

bool DigitalSharp::isInRange()
{
    return !digitalRead(pin);
}

//--------------------------------------

/*---------------------------------------
Class Ultrasonic
*/

class Ultrasonic
{
public:
    Ultrasonic(int);

    float getDistance();

private:
    int pingPin;
    NewPing sonar;
    
};

Ultrasonic::Ultrasonic(int pin) :
sonar(pin,pin)
{
     pingPin = pin;      
}

float Ultrasonic::getDistance()
{
    unsigned int microSec = sonar.ping();
    return float(microSec)/(US_ROUNDTRIP_CM);  
}


//--------------------------------------

/*---------------------------------------
Class Motor
*/

class Motor
{
public:
    Motor(int, int, int, int);
  
    int getEncoderA() {return encoderA;}
    int getEncoderB() {return encoderB;}
    unsigned long long getOldPos() {return oldPos;}
    int getLastStateA() {return lastStateA;}
    unsigned long long getEncoderPos() {return encoderPos;}
    
    void setEncoderPos(unsigned long long pos) {encoderPos = pos;}
    void setLastStateA(int state) {lastStateA = state;}
  
    float calcularVelocidad();
    void forward();
    void backward();
  
private:
    int pinAdelante;
    int pinAtras;
    int encoderA;
    int encoderB;
    float velocidad;
    volatile unsigned long long encoderPos;
    volatile int currentState = LOW;
    volatile int lastStateA  = LOW;

    unsigned long long oldTime;
    unsigned long long oldPos;
};

Motor::Motor(int pin1, int pin2, int eA, int eB)
{
    pinAdelante = pin1;
    pinAtras = pin2;
  
    encoderA = eA;
    encoderB = eB;
    
    pinMode(pinAdelante, OUTPUT);
    pinMode(pinAtras, OUTPUT);
    
    pinMode(encoderA, INPUT);
    digitalWrite(encoderA, HIGH);
    
    pinMode(encoderB, INPUT);
    digitalWrite(encoderB, HIGH);
  
    velocidad = 0;
    encoderPos = 0;
    
    oldTime = 0;
    oldPos;
}

float Motor::calcularVelocidad()
{
   unsigned long long newTime = millis();
  
   //newTime = newTime % 10000007;
   velocidad = ((encoderPos - oldPos)*1000)/((float)(newTime-oldTime));
   oldTime = newTime;
   oldPos = encoderPos;
   return velocidad; 
}

void Motor::forward()
{
    analogWrite(pinAdelante, 150);
    analogWrite(pinAtras, 0);
}

void Motor::backward()
{
    analogWrite(pinAdelante, 0);
    analogWrite(pinAtras, 150);
}

//------------------------------------------------


//VARIABLES
volatile int currentState = LOW;
volatile int lastStateA  = LOW;

Motor motor1(5,4,19,25);
Motor motor2(6,7,18,24);
Motor motor3(8,9,3,23);
Motor motor4(11,10,2,22);

volatile long motor1Pos = 0;
volatile long motor2Pos = 0;
volatile long motor3Pos = 0;
volatile long motor4Pos = 0;

float velocidadMotor1 = 0;
float velocidadMotor2 = 0;
float velocidadMotor3 = 0;
float velocidadMotor4 = 0;

Ultrasonic ultraSensor(A9);
DigitalSharp sharpSensor(A6);

//INTERRUPTS
void encodeInterruptM1()
{   
    currentState = digitalRead(motor1.getEncoderA());
    if(currentState == HIGH)
    {
        motor1Pos++;
    }

    motor1.setEncoderPos(motor1Pos);
    motor1.setLastStateA(currentState);
}

void encodeInterruptM2()
{
    currentState = digitalRead(motor2.getEncoderA());
    if(currentState == HIGH)
    {
        motor2Pos++;
    }

    motor2.setEncoderPos(motor2Pos);
    motor2.setLastStateA(currentState);
}

void encodeInterruptM3()
{
    currentState = digitalRead(motor3.getEncoderA());
    if(currentState == HIGH)
    {
        motor3Pos++;
    }

    motor3.setEncoderPos(motor3Pos);
    motor3.setLastStateA(currentState);
}

void encodeInterruptM4()
{
    currentState = digitalRead(motor4.getEncoderA());
    if(currentState == HIGH)
    {
        motor4Pos++;
    }

    motor4.setEncoderPos(motor4Pos);
    motor4.setLastStateA(currentState);
}
//----------------------------------------------

//--------------------------------------------
//Motor Move functions
void forward()
{
    motor1.forward();
    motor2.forward();
    motor3.forward();
    motor4.forward();

    velocidadMotor1 = motor1.calcularVelocidad();
    velocidadMotor2 = motor2.calcularVelocidad();
    velocidadMotor3 = motor3.calcularVelocidad();
    velocidadMotor4 = motor4.calcularVelocidad();
}

void backward()
{
    motor1.backward();
    motor2.backward();
    motor3.backward();
    motor4.backward();
}

void rotate(bool isRight)
{
    if(isRight)
    {
        motor1.forward();
        motor4.forward();
        motor3.backward();
        motor2.backward();
    }
    else
    {
        motor1.backward();
        motor2.backward();
        motor3.forward();
        motor4.forward();
    }
}

void setup() {

    enableInterrupt(motor1.getEncoderA(), encodeInterruptM1, CHANGE);
    enableInterrupt(motor1.getEncoderB(), encodeInterruptM1, CHANGE);
    enableInterrupt(motor2.getEncoderA(), encodeInterruptM2, CHANGE);
    enableInterrupt(motor2.getEncoderB(), encodeInterruptM2, CHANGE);
    enableInterrupt(motor3.getEncoderA(), encodeInterruptM3, CHANGE);
    enableInterrupt(motor3.getEncoderB(), encodeInterruptM3, CHANGE);
    enableInterrupt(motor4.getEncoderA(), encodeInterruptM4, CHANGE);
    enableInterrupt(motor4.getEncoderB(), encodeInterruptM4, CHANGE);
  
    Serial.begin(9600);
}

void loop() {
 
    if (sharpSensor.isInRange())
    {
        Serial.println("En rango");    
    }
    else
    {
        Serial.println("Fuera de rango");
    }
    
}

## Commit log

2017-12-21 Add files via upload
    80%
    [MazeBoard.brd, MazeBoard.sch]
2018-03-09 Added robot code
    [MazeBoard.brd, MazeBoard.sch]
2018-03-10 Added Sensors classes
2018-03-10 Added rotation by encoders
2018-03-11 Added forward by 30 cm
2018-03-15 Fixed side scanning algorithm
    [mazeRobot.ino]
2018-03-20 Added sensors scanning and aligning
2018-03-20 Added color sensor
2018-03-22 Fixed color sensor bug
    [mazeRobot.ino]
2018-03-22 Added checkpoint button functionality
2018-12-19 New link for the same CAD

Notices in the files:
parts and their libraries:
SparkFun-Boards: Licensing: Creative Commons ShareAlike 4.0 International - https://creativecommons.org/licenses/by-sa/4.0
